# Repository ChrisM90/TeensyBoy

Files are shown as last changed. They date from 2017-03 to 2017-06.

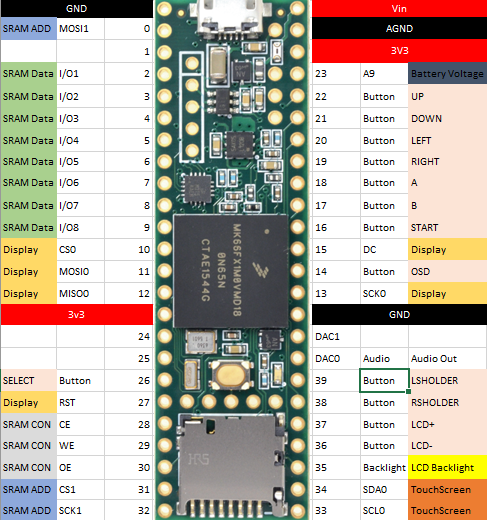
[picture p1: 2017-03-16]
Teensy Pinout.PNG

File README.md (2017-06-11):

New best FPS achieved 5.7 :-) 

First revision PCB design complete and awaiting fabrication.

Do To's:

1) Finish sound implementation.
2) Serious optimization and code cleanup.
3) Gameboy colour compatibility.
4) Cartridge connector to play real games?
5) Functionality to rip ROM's to SD card?
6) Proper hardware explanation and documentation.

If you feel inclined to donate:
Bitcoin:  1EkhsVgQydefFFrJgEuCpkJ9TY6QsAo3og

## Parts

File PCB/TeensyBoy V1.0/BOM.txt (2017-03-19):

Part     Value          Package

A        DTS-3          DTS-3
B        DTS-3          DTS-3
C1       100nf          C0603K
C2       10uf           C0603K
C3       10uf           C0603K
C4       220nf          C0603K
C5       330nf          C0603K
DOWN     DTS-3          DTS-3
JP1                     1X10
LEFT     DTS-3          DTS-3
Q1       2N2222A        TO18
R1       1K             R0603
R2       4K7            R0603
R3       10K            R0603
R4       10K            R0603
R5       10K            R0603
R6       10K            R0603
R7       10K            R0603
R8       10K            R0603
R9       10K            R0603
R10      10K            R0603
R11      100K           R0603
R13      27K            CT6
RIGHT    DTS-3          DTS-3
SELECT   DTS-3          DTS-3
SPK                     1X02
START    DTS-3          DTS-3 
U$1      AS7C34096A     AS7C34096A
U$2                     TEENSY-3.6_FULL
U1       LM4875         SO-8
UP       DTS-3          DTS-3

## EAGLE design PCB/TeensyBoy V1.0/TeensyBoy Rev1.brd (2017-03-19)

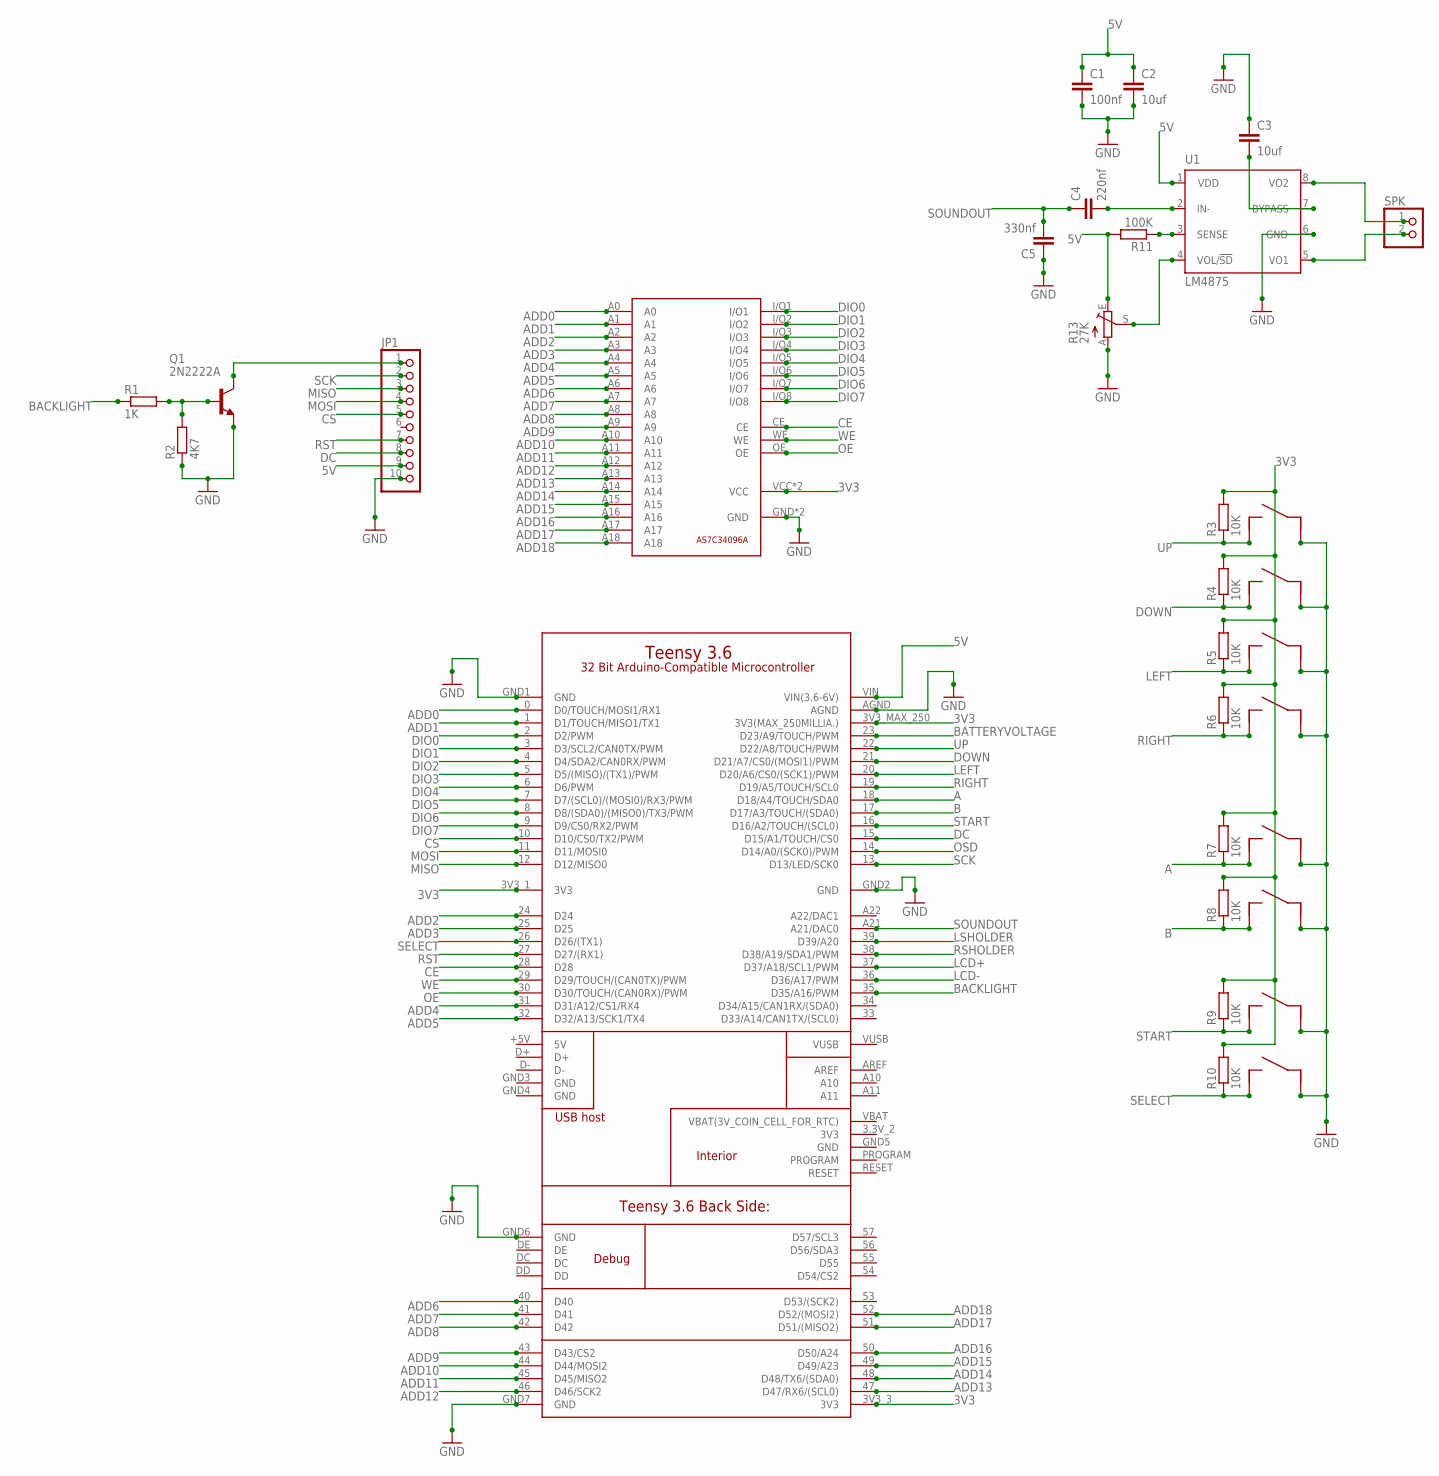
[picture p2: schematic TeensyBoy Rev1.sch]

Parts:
A: DTS-3
B: DTS-3
C1: 100nf; C0603K
C2, C3: 10uf; C0603K
C4: 220nf; C0603K
C5: 330nf; C0603K
DOWN: DTS-3
JP1: PINHD-1X10; 1X10
LEFT: DTS-3
Q1: 2N2222A; TO18
R1: 1K; R0603
R2: 4K7; R0603
R3, R4, R5, R6, R7, R8, R9, R10: 10K; R0603
R11: 100K; R0603
R13: 27K; CT6
RIGHT: DTS-3
SELECT: DTS-3
SPK: PINHD-1X2; 1X02
START: DTS-3
U1: LM4875; SO-8
U$1: AS7C34096A
U$2: TEENSY-3.6_FULL
UP: DTS-3

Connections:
3V3: R3.2, R4.2, R5.2, R6.2, R7.2, R8.2, R9.2, R10.2, U$1.VCC, U$1.VCC0 (VCC), U$2.3V3_1 (3V3), U$2.3V3_3 (3V3), U$2.3V3_MAX_250 (3V3(MAX_250MILLIA.))
5V: C1.1, C2.1, JP1.9, R11.2, R13.E, U1.1 (VDD), U$2.VIN (VIN(3.6-6V))
A: A.P$1, R7.1, U$2.18 (D18/A4/TOUCH/SDA0)
ADD0: U$1.A0, U$2.0 (D0/TOUCH/MOSI1/RX1)
ADD1: U$1.A1, U$2.1 (D1/TOUCH/MISO1/TX1)
ADD2: U$1.A2, U$2.24 (D24)
ADD3: U$1.A3, U$2.25 (D25)
ADD4: U$1.A4, U$2.31 (D31/A12/CS1/RX4)
ADD5: U$1.A5, U$2.32 (D32/A13/SCK1/TX4)
ADD6: U$1.A6, U$2.40 (D40)
ADD7: U$1.A7, U$2.41 (D41)
ADD8: U$1.A8, U$2.42 (D42)
ADD9: U$1.A9, U$2.43 (D43/CS2)
ADD10: U$1.A10, U$2.44 (D44/MOSI2)
ADD11: U$1.A11, U$2.45 (D45/MISO2)
ADD12: U$1.A12, U$2.46 (D46/SCK2)
ADD13: U$1.A13, U$2.47 (D47/RX6/(SCL0))
ADD14: U$1.A14, U$2.48 (D48/TX6/(SDA0))
ADD15: U$1.A15, U$2.49 (D49/A23)
ADD16: U$1.A16, U$2.50 (D50/A24)
ADD17: U$1.A17, U$2.51 (D51/(MISO2))
ADD18: U$1.A18, U$2.52 (D52/(MOSI2))
B: B.P$1, R8.1, U$2.17 (D17/A3/TOUCH/(SDA0))
BACKLIGHT: R1.1, U$2.35 (D35/A16/PWM)
BATTERYVOLTAGE: U$2.23 (D23/A9/TOUCH/PWM)
CE: U$1.CE, U$2.28 (D28)
CS: JP1.5, U$2.10 (D10/CS0/TX2/PWM)
DC: JP1.8, U$2.15 (D15/A1/TOUCH/CS0)
DIO0: U$1.I/O1, U$2.2 (D2/PWM)
DIO1: U$1.I/O2, U$2.3 (D3/SCL2/CAN0TX/PWM)
DIO2: U$1.I/O3, U$2.4 (D4/SDA2/CAN0RX/PWM)
DIO3: U$1.I/O4, U$2.5 (D5/(MISO)/(TX1)/PWM)
DIO4: U$1.I/O5, U$2.6 (D6/PWM)
DIO5: U$1.I/O6, U$2.7 (D7/(SCL0)/(MOSI0)/RX3/PWM)
DIO6: U$1.I/O7, U$2.8 (D8/(SDA0)/(MISO0)/TX3/PWM)
DIO7: U$1.I/O8, U$2.9 (D9/CS0/RX2/PWM)
DOWN: DOWN.P$1, R4.1, U$2.21 (D21/A7/CS0/(MOSI1)/PWM)
GND: A.P$2, B.P$2, C1.2, C2.2, C3.1, C5.1, DOWN.P$2, JP1.10, LEFT.P$2, Q1.1 (E), R2.1, R13.A, RIGHT.P$2, SELECT.P$2, START.P$2, U1.6 (GND), U$1.GND, U$1.GND0 (GND), U$2.AGND, U$2.GND1 (GND), U$2.GND2 (GND), U$2.GND6 (GND), U$2.GND7 (GND), UP.P$2
LCD+: U$2.37 (D37/A18/SCL1/PWM)
LCD-: U$2.36 (D36/A17/PWM)
LEFT: LEFT.P$1, R5.1, U$2.20 (D20/A6/CS0/(SCK1)/PWM)
LSHOLDER: U$2.39 (D39/A20)
MISO: JP1.3, U$2.12 (D12/MISO0)
MOSI: JP1.4, U$2.11 (D11/MOSI0)
unnamed: JP1.1, Q1.3 (C)
unnamed: Q1.2 (B), R1.2, R2.2
unnamed: C3.2, U1.7 (BYPASS)
unnamed: C4.2, U1.2 (IN-)
unnamed: R11.1, U1.3 (SENSE)
unnamed: SPK.1, U1.8 (VO2)
unnamed: SPK.2, U1.5 (VO1)
unnamed: R13.S, U1.4 (VOL/!SD)
OE: U$1.OE, U$2.30 (D30/TOUCH/(CAN0RX)/PWM)
OSD: U$2.14 (D14/A0/(SCK0)/PWM)
RIGHT: R6.1, RIGHT.P$1, U$2.19 (D19/A5/TOUCH/SCL0)
RSHOLDER: U$2.38 (D38/A19/SDA1/PWM)
RST: JP1.7, U$2.27 (D27/(RX1))
SCK: JP1.2, U$2.13 (D13/LED/SCK0)
SELECT: R10.1, SELECT.P$1, U$2.26 (D26/(TX1))
SOUNDOUT: C4.1, C5.2, U$2.A21 (A21/DAC0)
START: R9.1, START.P$1, U$2.16 (D16/A2/TOUCH/(SCL0))
UP: R3.1, U$2.22 (D22/A8/TOUCH/PWM), UP.P$1
WE: U$1.WE, U$2.29 (D29/TOUCH/(CAN0TX)/PWM)

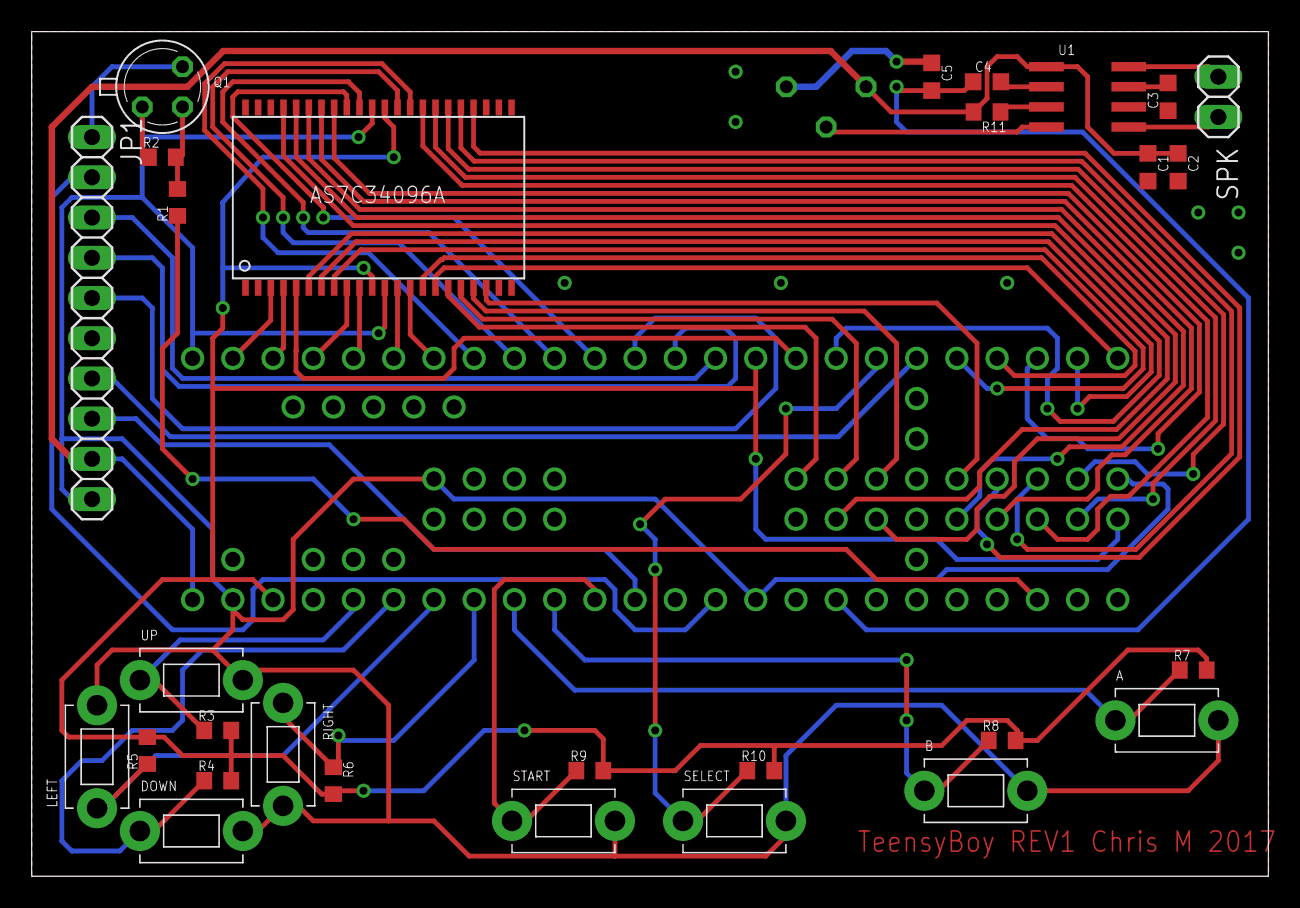
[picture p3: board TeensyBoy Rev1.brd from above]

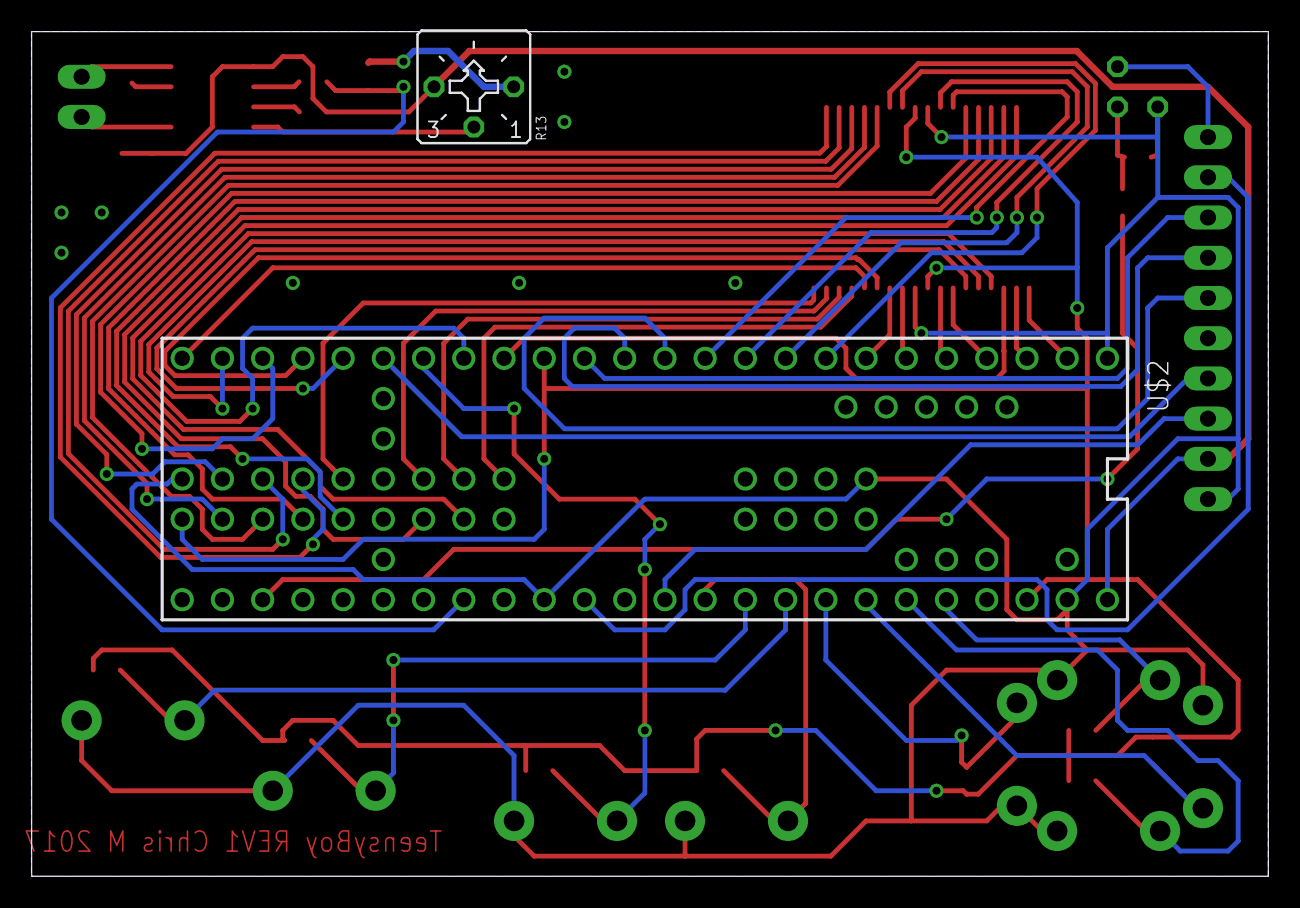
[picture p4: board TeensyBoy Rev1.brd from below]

Board: 2 copper layers, 78.1 x 53.3 mm, 31 parts (2 on the bottom side), 57 nets.

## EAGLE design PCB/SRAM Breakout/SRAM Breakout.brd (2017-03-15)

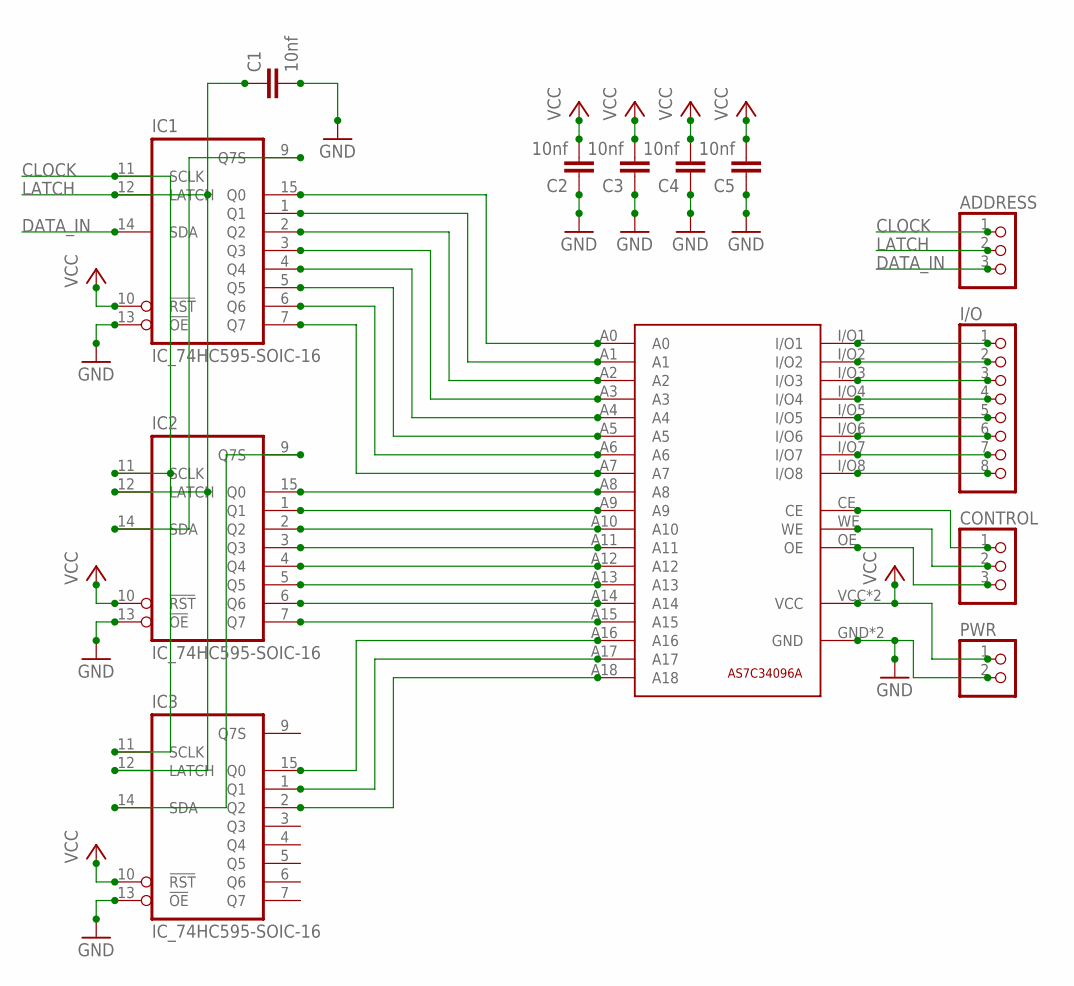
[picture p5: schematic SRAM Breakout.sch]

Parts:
ADDRESS: PINHD-1X3/90; 1X03/90
C1, C2, C3, C4, C5: 10nf; C0603
CONTROL: PINHD-1X3/90; 1X03/90
I/O: PINHD-1X8/90; 1X08/90
IC1, IC2, IC3: IC_74HC595-SOIC-16; SOIC-16
PWR: PINHD-1X2/90; 1X02/90
U$1: AS7C34096A

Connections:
CLOCK: ADDRESS.1, IC1.11 (SCLK), IC2.11 (SCLK), IC3.11 (SCLK)
DATA_IN: ADDRESS.3, IC1.14 (SDA)
GND: C1.2, C2.1, C3.1, C4.1, C5.1, IC1.13 (!OE), IC2.13 (!OE), IC3.13 (!OE), PWR.2, U$1.GND, U$1.GND0 (GND)
LATCH: ADDRESS.2, C1.1, IC1.12 (LATCH), IC2.12 (LATCH), IC3.12 (LATCH)
unnamed: IC1.9 (Q7S), IC2.14 (SDA)
unnamed: IC2.9 (Q7S), IC3.14 (SDA)
unnamed: I/O.1, U$1.I/O1
unnamed: IC1.15 (Q0), U$1.A0
unnamed: IC1.1 (Q1), U$1.A1
unnamed: IC1.2 (Q2), U$1.A2
unnamed: IC1.3 (Q3), U$1.A3
unnamed: IC1.4 (Q4), U$1.A4
unnamed: IC1.5 (Q5), U$1.A5
unnamed: IC1.6 (Q6), U$1.A6
unnamed: IC1.7 (Q7), U$1.A7
unnamed: IC2.15 (Q0), U$1.A8
unnamed: IC2.1 (Q1), U$1.A9
unnamed: IC2.2 (Q2), U$1.A10
unnamed: IC2.3 (Q3), U$1.A11
unnamed: IC2.4 (Q4), U$1.A12
unnamed: IC2.5 (Q5), U$1.A13
unnamed: IC2.6 (Q6), U$1.A14
unnamed: IC2.7 (Q7), U$1.A15
unnamed: IC3.15 (Q0), U$1.A16
unnamed: IC3.1 (Q1), U$1.A17
unnamed: IC3.2 (Q2), U$1.A18
unnamed: I/O.2, U$1.I/O2
unnamed: I/O.3, U$1.I/O3
unnamed: I/O.4, U$1.I/O4
unnamed: I/O.5, U$1.I/O5
unnamed: I/O.6, U$1.I/O6
unnamed: I/O.7, U$1.I/O7
unnamed: I/O.8, U$1.I/O8
unnamed: CONTROL.1, U$1.CE
unnamed: CONTROL.2, U$1.WE
unnamed: CONTROL.3, U$1.OE
VCC: C2.2, C3.2, C4.2, C5.2, IC1.10 (!RST), IC2.10 (!RST), IC3.10 (!RST), PWR.1, U$1.VCC, U$1.VCC0 (VCC)

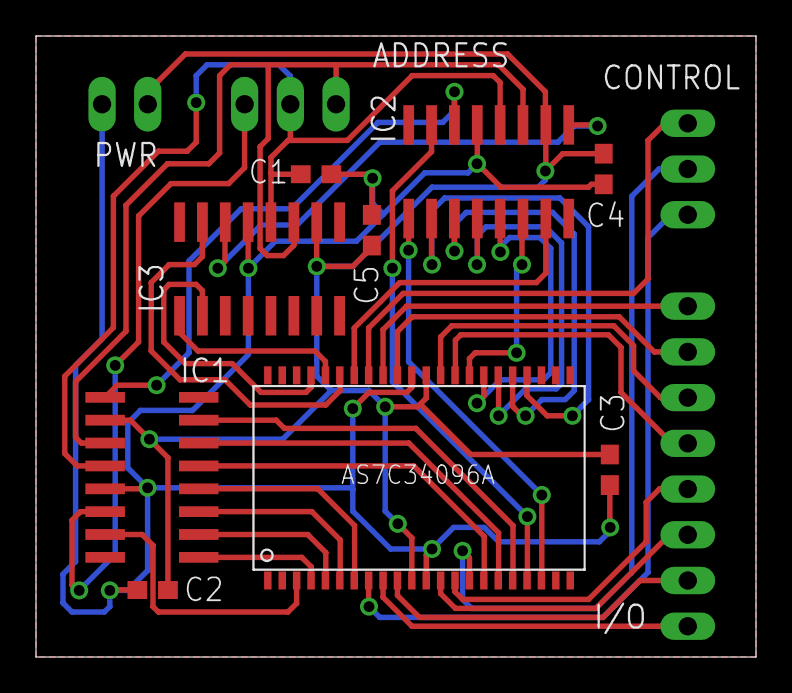
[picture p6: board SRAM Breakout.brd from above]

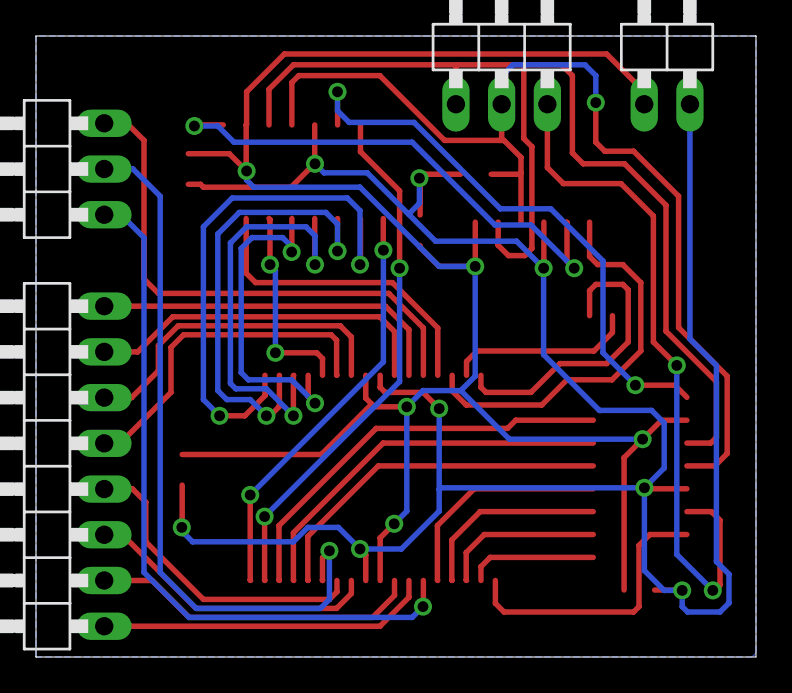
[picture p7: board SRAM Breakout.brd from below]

Board: 2 copper layers, 40.0 x 34.5 mm, 13 parts (4 on the bottom side), 37 nets.

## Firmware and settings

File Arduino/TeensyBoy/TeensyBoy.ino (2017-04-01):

/* TeenyBoy code is placed under the MIT license
   Copyright (c) 2017 Chris Mortimer

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
   THE SOFTWARE IS PROVIDED "AS IS", WITHOUT WARRANTY OF ANY KIND,
   EXPRESS OR IMPLIED, INCLUDING BUT NOT LIMITED TO THE WARRANTIES OF
   MERCHANTABILITY, FITNESS FOR A PARTICULAR PURPOSE AND
   NONINFRINGEMENT. IN NO EVENT SHALL THE AUTHORS OR COPYRIGHT HOLDERS
   BE LIABLE FOR ANY CLAIM, DAMAGES OR OTHER LIABILITY, WHETHER IN AN
   ACTION OF CONTRACT, TORT OR OTHERWISE, ARISING FROM, OUT OF OR IN
   CONNECTION WITH THE SOFTWARE OR THE USE OR OTHER DEALINGS IN THE
   SOFTWARE.
*/
#include <SD.h>
#include <SD_t3.h>
#include <SPI.h>
#include "GBA.h"
#include "GBC.h"

File FROM;
GBA GBAEmulator;

void setup()
{
  delay(2000);
  
  Serial.begin(250000);
  
  SD.begin(BUILTIN_SDCARD);
  FROM = SD.open("/MK/MK.gba", FILE_READ);

  GBAEmulator.Initilise(&FROM);

  ARM_DEMCR |= ARM_DEMCR_TRCENA;
  ARM_DWT_CTRL |= ARM_DWT_CTRL_CYCCNTENA;

  Serial.println("Checking and Resetting Memory...");
  Serial.flush();

  unsigned long WriteTime = 0.0;
  unsigned long ReadTime = 0.0;
  unsigned long WriteTimeSeq = 0.0;
  unsigned long ReadTimeSeq = 0.0;
  unsigned long AddressTime = 0.0;
  unsigned long AddressTimeSeq = 0.0;
  unsigned long Timer = 0;

  for(int i = 0; i < 30; i++)
  {
    Timer = ARM_DWT_CYCCNT;
    SPIRAMWrite((i * 10), 128);
    Timer = ARM_DWT_CYCCNT - Timer;
    WriteTime += Timer;
  
    Timer = ARM_DWT_CYCCNT;
    SPIRAMWrite((i * 10) + 1, 128);
    Timer = ARM_DWT_CYCCNT - Timer;
    WriteTimeSeq += Timer;
    
    Timer = ARM_DWT_CYCCNT;
    SPIRAMRead((i * 10));
    Timer = ARM_DWT_CYCCNT - Timer;
    ReadTime += Timer;
  
    Timer = ARM_DWT_CYCCNT;
    SPIRAMRead((i * 10) + 1);
    Timer = ARM_DWT_CYCCNT - Timer;
    ReadTimeSeq += Timer;

    Timer = ARM_DWT_CYCCNT;
    SetAddress((i * 10));
    Timer = ARM_DWT_CYCCNT - Timer;
    AddressTime += Timer;

    Timer = ARM_DWT_CYCCNT;
    SetAddress((i * 10) + 1);
    Timer = ARM_DWT_CYCCNT - Timer;
    AddressTimeSeq += Timer;

    SPIRAMRead(0);
  }

  float timemulti = 1.0f / 240; //1 us divided by 240Mhz

  Serial.println("Memory Read Time: " + String(((float)ReadTime / 30.0f) * timemulti) + "us");
  Serial.println("Memory Write Time: " + String(((float)WriteTime / 30.0f) * timemulti) + "us");
  
  Serial.println("Memory Read Time Seq: " + String(((float)ReadTimeSeq / 30.0f) * timemulti) + "us");
  Serial.println("Memory Write Time Seq: " + String(((float)WriteTimeSeq / 30.0f) * timemulti) + "us");

  Serial.println("Memory Address Time: " + String(((float)AddressTime / 30.0f) * timemulti) + "us");
  Serial.println("Memory Address Time Seq: " + String(((float)AddressTimeSeq / 30.0f) * timemulti) + "us");
  
  while(true)
  {
    uint8_t val = 0;
    bool failed = false;
    for(uint32_t i = 0; i < 0x80000; i++)
    {
      SPIRAMWrite(i, val);
      uint8_t value = SPIRAMRead(i);
  
      if(value != val)
      {
        Serial.println("Memory Check Failed at :" + String(i, DEC) + " W: " + String(val, DEC) + " R: " + String(value, DEC));
        Serial.flush();
        failed = true;
        break;
      }
      SPIRAMWrite(i, 0);
      val++;
    }
    
    if(!failed)
    {
      Serial.println("Ram Test: Passed");
      break;
    }
  
    delay(1000);
  }
  
  Serial.println("Init Complete");
  Serial.println("Emulation Starting..");
}

void loop()
{
  GBAEmulator.Update();
}

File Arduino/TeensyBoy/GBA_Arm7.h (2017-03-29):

/* TeenyBoy code is placed under the MIT license
   Copyright (c) 2017 Chris Mortimer

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
   THE SOFTWARE IS PROVIDED "AS IS", WITHOUT WARRANTY OF ANY KIND,
   EXPRESS OR IMPLIED, INCLUDING BUT NOT LIMITED TO THE WARRANTIES OF
   MERCHANTABILITY, FITNESS FOR A PARTICULAR PURPOSE AND
   NONINFRINGEMENT. IN NO EVENT SHALL THE AUTHORS OR COPYRIGHT HOLDERS
   BE LIABLE FOR ANY CLAIM, DAMAGES OR OTHER LIABILITY, WHETHER IN AN
   ACTION OF CONTRACT, TORT OR OTHERWISE, ARISING FROM, OUT OF OR IN
   CONNECTION WITH THE SOFTWARE OR THE USE OR OTHER DEALINGS IN THE
   SOFTWARE.
*/

#ifndef Arm7_h
#define Arm7_h

#include <inttypes.h>
#include <Arduino.h>

#define REG_BASE 0x4000000
#define PAL_BASE 0x5000000
#define VRAM_BASE 0x6000000
#define OAM_BASE 0x7000000

#define DISPSTAT 0x4
#define VCOUNT 0x6

#define BG0CNT 0x8
#define BG1CNT 0xA
#define BG2CNT 0xC
#define BG3CNT 0xE

#define BG0HOFS 0x10
#define BG0VOFS 0x12
#define BG1HOFS 0x14
#define BG1VOFS 0x16
#define BG2HOFS 0x18
#define BG2VOFS 0x1A
#define BG3HOFS 0x1C
#define BG3VOFS 0x1E

#define BG2PA 0x20
#define BG2PB 0x22
#define BG2PC 0x24
#define BG2PD 0x26
#define BG2X_L 0x28
#define BG2X_H 0x2A
#define BG2Y_L 0x2C
#define BG2Y_H 0x2E
#define BG3PA 0x30
#define BG3PB 0x32
#define BG3PC 0x34
#define BG3PD 0x36
#define BG3X_L 0x38
#define BG3X_H 0x3A
#define BG3Y_L 0x3C
#define BG3Y_H 0x3E

#define BLDCNT 0x50
#define BLDALPHA 0x52
#define BLDY 0x54

#define SOUNDCNT_L 0x80
#define SOUNDCNT_H 0x82
#define SOUNDCNT_X 0x84

#define FIFO_A_L 0xA0
#define FIFO_A_H 0xA2
#define FIFO_B_L 0xA4
#define FIFO_B_H 0xA6

#define DMA0SAD 0xB0
#define DMA0DAD 0xB4
#define DMA0CNT_L 0xB8
#define DMA0CNT_H 0xBA
#define DMA1SAD 0xBC
#define DMA1DAD 0xC0
#define DMA1CNT_L 0xC4
#define DMA1CNT_H 0xC6
#define DMA2SAD 0xC8
#define DMA2DAD 0xCC
#define DMA2CNT_L 0xD0
#define DMA2CNT_H 0xD2
#define DMA3SAD 0xD4
#define DMA3DAD 0xD8
#define DMA3CNT_L 0xDC
#define DMA3CNT_H 0xDE

#define TM0D 0x100
#define TM0CNT 0x102
#define TM1D 0x104
#define TM1CNT 0x106
#define TM2D 0x108
#define TM2CNT 0x10A
#define TM3D 0x10C
#define TM3CNT 0x10E

#define KEYINPUT 0x130
#define KEYCNT 0x132
#define IE0 0x200
#define IF 0x202
#define IME 0x208

#define HALTCNT 0x300

#define biosRamMask 0x3FFF //BIOS ROM 16KB
#define ewRamMask 0x3FFFF  //External Work Ram 256KB
#define iwRamMask 0x7FFF   //Internal MCU Memory 32KB
#define ioRegMask 0x4FF    //IO RAM 1KB 
#define vRamMask 0x1FFFF   //Video RAM 96KB
#define palRamMask 0x3FF   //Palettes RAM 1KB
#define oamRamMask 0x3FF   //Object Attribute RAM 1KB
#define sRamMask 0xFFFF    //Cartridge RAM 64KB
#define eeMask 0xFFFF

#define ewRamStart  0x00000000 //0x00000 - 0x3FFFF = 0x3FFFF
#define iwRamStart  0x00040000 //0x40000 - 0x47FFF = 0x7FFF
#define ioRegStart  0x00048000 //0x48000 - 0x484FF = 0x4FF
#define vRamStart   0x00048500 //0x48500 - 0x684FF = 0x1FFFF
#define palRamStart 0x00068500 //0x68500 - 0x688FF = 0x3FF
#define oamRamStart 0x00068900 //0x68900 - 0x68CFF = 0x3FF
#define sRamStart   0x00068D00 //0x68D00 - 0x78CFF = 0xFFFF
#define eeStart     0x00078D00 //0x78D00 - 0x88CFF = 0xFFFF

class Processor
{
  public:
    //Variables
    //CPSR Bit Definitions
    uint32_t N_BIT = 31;
    uint32_t Z_BIT = 30;
    uint32_t C_BIT = 29;
    uint32_t V_BIT = 28;
    uint32_t I_BIT = 7;
    uint32_t F_BIT = 6;
    uint32_t T_BIT = 5;
    
    uint32_t N_MASK = (1 << N_BIT);
    uint32_t Z_MASK = (1 << Z_BIT);
    uint32_t C_MASK = (1 << C_BIT);
    uint32_t V_MASK = (1 << V_BIT);
    uint32_t I_MASK = (1 << I_BIT);
    uint32_t F_MASK = (1 << F_BIT);
    uint32_t T_MASK = (1 << T_BIT);

    int32_t Cycles = 0;
    int32_t timerCycles = 0;
    int32_t soundCycles = 0;
    uint32_t registers[16];
    uint32_t cpsr = 0;
    uint32_t waitCycles = 0;
    int32_t bgx[2];
    int32_t bgy[2];
    bool cpuHalted = false;
    uint8_t OAMRAM[0x3FF];
    uint8_t IOREG[0x4FF];
    uint16_t keyState = 0x3FF;

    //Methods
    Processor();
    void Print(const char* value, uint32_t v);
    void CreateCores(class Processor *par, class File *rom, bool SkipBios);
    bool ArmState();
    bool SPSRExists();
    uint32_t GetWaitCycles();
    uint32_t GetSPSR();
    void SetSPSR(uint32_t value);
    void SwapRegsHelper(uint32_t swapRegs[]);
    void SwapRegisters(uint32_t bank);
    void WriteCpsr(uint32_t newCpsr);
    void EnterException(uint32_t mode, uint32_t vector, bool interruptDisabled, bool fiqDisabled);
    void RequestIrq(uint16_t irq);
    void FireIrq();
    void Reset(bool skipBios);
    void Halt();
    void ReloadQueue();
    void UpdateTimer(uint16_t timer, uint32_t cycles, bool countUp);
    void UpdateTimers();
    void UpdateKeyState();
    void UpdateSound();
    void Execute(int cycles);

    void Reset();
    
    void HBlankDma();
    void VBlankDma();
    void FifoDma(uint8_t channel);
    void DmaTransfer(uint8_t channel);
    void WriteDmaControl(uint8_t channel);
    void WriteTimerControl(uint32_t timer, uint32_t newCnt);
    
    uint8_t ReadU8(uint32_t address, uint32_t RAMRange);
    uint16_t ReadU16(uint32_t address, uint32_t RAMRange);
    uint32_t ReadU32(uint32_t address, uint32_t RAMRange);
    
    void WriteU8(uint32_t address, uint32_t RAMRange, uint8_t value);
    void WriteU16(uint32_t address, uint32_t RAMRange, uint16_t value);
    void WriteU32(uint32_t address, uint32_t RAMRange, uint32_t value);
    
    uint32_t ReadUnreadable();
    uint8_t ReadNop8(uint32_t address);
    uint16_t ReadNop16(uint32_t address);
    uint32_t ReadNop32(uint32_t address);
    uint8_t  ReadBIOS8(uint32_t address);
    uint16_t ReadBIOS16(uint32_t address);
    uint32_t ReadBIOS32(uint32_t address);
    uint8_t ReadEwRam8(uint32_t address);
    uint16_t ReadEwRam16(uint32_t address);
    uint32_t ReadEwRam32(uint32_t address);
    uint8_t ReadIwRam8(uint32_t address);
    uint16_t ReadIwRam16(uint32_t address);
    uint32_t ReadIwRam32(uint32_t address);
    uint8_t ReadIO8(uint32_t address);
    uint16_t ReadIO16(uint32_t address);
    uint32_t ReadIO32(uint32_t address);
    uint8_t ReadPalRam8(uint32_t address);
    uint16_t ReadPalRam16(uint32_t address);
    uint32_t ReadPalRam32(uint32_t address);
    uint8_t ReadVRam8(uint32_t address);
    uint16_t ReadVRam16(uint32_t address);
    uint32_t ReadVRam32(uint32_t address);
    uint8_t ReadOamRam8(uint32_t address);
    uint16_t ReadOamRam16(uint32_t address);
    uint32_t ReadOamRam32(uint32_t address);
    uint8_t  ReadROM8(uint32_t address, uint8_t bank);
    uint16_t ReadROM16(uint32_t address, uint8_t bank);
    uint32_t ReadROM32(uint32_t address, uint8_t bank);
    uint8_t ReadSRam8(uint32_t address);
    uint16_t ReadSRam16(uint32_t address);
    uint32_t ReadSRam32(uint32_t address);
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

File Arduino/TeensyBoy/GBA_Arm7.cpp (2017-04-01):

/* TeenyBoy code is placed under the MIT license
   Copyright (c) 2017 Chris Mortimer

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
   THE SOFTWARE IS PROVIDED "AS IS", WITHOUT WARRANTY OF ANY KIND,
   EXPRESS OR IMPLIED, INCLUDING BUT NOT LIMITED TO THE WARRANTIES OF
   MERCHANTABILITY, FITNESS FOR A PARTICULAR PURPOSE AND
   NONINFRINGEMENT. IN NO EVENT SHALL THE AUTHORS OR COPYRIGHT HOLDERS
   BE LIABLE FOR ANY CLAIM, DAMAGES OR OTHER LIABILITY, WHETHER IN AN
   ACTION OF CONTRACT, TORT OR OTHERWISE, ARISING FROM, OUT OF OR IN
   CONNECTION WITH THE SOFTWARE OR THE USE OR OTHER DEALINGS IN THE
   SOFTWARE.
*/

#include "GBA_Arm7.h"
#include "GBA_ArmCore.h"
#include "GBA_ThumbCore.h"
#include "Bios.h"
#include "GBA_SoundManager.h"
#include <SD.h>
#include <SD_t3.h>

//---------------------Memory----------------------------//
bool inUnreadable = false;
uint32_t dmaRegs[4][4];
uint32_t timerCnt[4];

uint32_t romBank1Mask = 0;
uint32_t romBank2Mask = 0;
uint32_t bankSTimes[0x10];
uint32_t bankNTimes[0x10];
uint8_t RomBankCount = 0;

//-------------------------VGA--------------------------//

const uint8_t VramBlockSize = 64;
const uint8_t PalBlockSize = 32;
bool EnableVRUpdating = true;

//----------------------------CPU-----------------------//
//CPU Mode Definitions
const uint32_t USR = 0x10;
const uint32_t FIQ = 0x11;
const uint32_t IRQ = 0x12;
const uint32_t SVC = 0x13;
const uint32_t ABT = 0x17;
const uint32_t UND = 0x1B;
const uint32_t SYS = 0x1F;
    
//Bank Registers
uint32_t bankedFIQ[7];
uint32_t bankedIRQ[2];
uint32_t bankedSVC[2];
uint32_t bankedABT[2];
uint32_t bankedUND[2];

//Saved CPSR's
uint32_t spsrFIQ = 0;
uint32_t spsrIRQ = 0;
uint32_t spsrSVC = 0;
uint32_t spsrABT = 0;
uint32_t spsrUND = 0;

#define CE 28
#define WE 29
#define OE 30

#define DIO0 2 //D0
#define DIO1 3 //A12
#define DIO2 4 //A13
#define DIO3 5 //D7
#define DIO4 6 //D4
#define DIO5 7 //D2
#define DIO6 8 //D3
#define DIO7 9 //C3

#define ADD0 0   //B16
#define ADD1 1   //B17
#define ADD2 24  //E26
#define ADD3 25  //A5 
#define ADD4 31  //B10
#define ADD5 32  //B11
#define ADD6 40  //A28 
#define ADD7 41  //A29 
#define ADD8 42  //A26 
#define ADD9 43  //B20
#define ADD10 44 //B22
#define ADD11 45 //B23 
#define ADD12 46 //B21 
#define ADD13 47 //D8 
#define ADD14 48 //D9 
#define ADD15 49 //B4 
#define ADD16 50 //B5 
#define ADD17 51 //D14
#define ADD18 52 //D13

ArmCore armCore;
ThumbCore thumbCore;
SoundManager sound;
Processor *SelfReference;
File *ROM;

Processor::Processor()
{
  //Memory Data IO
  pinMode(DIO0, INPUT); //IO 0
  pinMode(DIO1, INPUT); //IO 1
  pinMode(DIO2, INPUT); //IO 2
  pinMode(DIO3, INPUT); //IO 3
  pinMode(DIO4, INPUT); //IO 4
  pinMode(DIO5, INPUT); //IO 5
  pinMode(DIO6, INPUT); //IO 6
  pinMode(DIO7, INPUT); //IO 7

  //Memory Control Default Read
  pinMode(CE, OUTPUT); //CE
  digitalWrite(CE, HIGH);
  pinMode(WE, OUTPUT); //WE
  digitalWrite(WE, HIGH);
  pinMode(OE, OUTPUT); //OE
  digitalWrite(OE, LOW);

  //Memory Address
  pinMode(ADD0, OUTPUT); //ADD 0
  pinMode(ADD1, OUTPUT); //ADD 1
  pinMode(ADD2, OUTPUT); //ADD 2
  pinMode(ADD3, OUTPUT); //ADD 3
  pinMode(ADD4, OUTPUT); //ADD 4
  pinMode(ADD5, OUTPUT); //ADD 5
  pinMode(ADD6, OUTPUT); //ADD 6
  pinMode(ADD7, OUTPUT); //ADD 7
  pinMode(ADD8, OUTPUT); //ADD 8
  pinMode(ADD9, OUTPUT); //ADD 9
  pinMode(ADD10, OUTPUT); //ADD 10
  pinMode(ADD11, OUTPUT); //ADD 11
  pinMode(ADD12, OUTPUT); //ADD 12
  pinMode(ADD13, OUTPUT); //ADD 13
  pinMode(ADD14, OUTPUT); //ADD 14
  pinMode(ADD15, OUTPUT); //ADD 15
  pinMode(ADD16, OUTPUT); //ADD 16
  pinMode(ADD17, OUTPUT); //ADD 17
  pinMode(ADD18, OUTPUT); //ADD 18

  digitalWrite(ADD0, LOW);
  digitalWrite(ADD1, LOW);
  digitalWrite(ADD2, LOW);
  digitalWrite(ADD3, LOW);
  digitalWrite(ADD4, LOW);
  digitalWrite(ADD5, LOW);
  digitalWrite(ADD6, LOW);
  digitalWrite(ADD7, LOW);
  digitalWrite(ADD8, LOW);
  digitalWrite(ADD9, LOW);
  digitalWrite(ADD10, LOW);
  digitalWrite(ADD11, LOW);
  digitalWrite(ADD12, LOW);
  digitalWrite(ADD13, LOW);
  digitalWrite(ADD14, LOW);
  digitalWrite(ADD15, LOW);
  digitalWrite(ADD16, LOW);
  digitalWrite(ADD17, LOW);
  digitalWrite(ADD18, LOW);
}

void Processor::CreateCores(class Processor *par, class File *rom, bool SkipBios)
{
  digitalWrite(CE, LOW);
  ROM = rom;
  SelfReference = par;
  armCore = ArmCore(SelfReference);
  thumbCore = ThumbCore(SelfReference);
  sound.StartSM(44100, SelfReference);
  LoadCartridge();
  Reset(SkipBios);
}

void Processor::Print(const char* value, uint32_t v)
{
  Serial.println(String(value) + " " + String(v, DEC));
}

bool Processor::ArmState()
{
  return (cpsr & T_MASK) != T_MASK;
}

bool Processor::SPSRExists()
{
  switch (cpsr & 0x1F)
  {
    case USR:
    case SYS:
      return false;
    case FIQ:
    case SVC:
    case ABT:
    case IRQ:
    case UND:
      return true;
    default:
      return false;
  }
}

uint32_t Processor::GetWaitCycles()
{
  uint32_t tmp = waitCycles;
  waitCycles = 0;
  return tmp;
}

uint32_t Processor::GetSPSR()
{
  switch (cpsr & 0x1f)
  {
    case USR:
    case SYS:
      return 0xFFFFFFFF;
    case FIQ:
      return spsrFIQ;
    case SVC:
      return spsrSVC;
    case ABT:
      return spsrABT;
    case IRQ:
      return spsrIRQ;
    case UND:
      return spsrUND;
    default:
      return 0; //Explode
  }
}

void Processor::SetSPSR(uint32_t value)
{
  switch (cpsr & 0x1f)
  {
    case USR:
    case SYS:
      break;
    case FIQ:
      spsrFIQ = value;
      break;
    case SVC:
      spsrSVC = value;
      break;
    case ABT:
      spsrABT = value;
      break;
    case IRQ:
      spsrIRQ = value;
      break;
    case UND:
      spsrUND = value;
      break;
  }
}

void Processor::SwapRegsHelper(uint32_t swapRegs[])
{
  uint8_t swapRegsLength = (sizeof(swapRegs)/sizeof(uint32_t));
  
  for(int32_t i = 14; i > (14 - swapRegsLength); i--)
  {
    uint32_t temp = registers[i];
    registers[i] = swapRegs[swapRegsLength - (14 -i) - 1];
    swapRegs[swapRegsLength - (14 - i) - 1] = temp;
  }
}

void Processor::SwapRegisters(uint32_t bank)
{
  switch (bank & 0x1F)
  {
    case FIQ:
      SwapRegsHelper(bankedFIQ);
      break;
    case SVC:
      SwapRegsHelper(bankedSVC);
      break;
    case ABT:
      SwapRegsHelper(bankedABT);
      break;
    case IRQ:
      SwapRegsHelper(bankedIRQ);
      break;
    case UND:
      SwapRegsHelper(bankedUND);
      break;
  }
}

void Processor::WriteCpsr(uint32_t newCpsr)
{
  if((newCpsr & 0x1F) != (cpsr & 0x1F))
  {
    //Swap out the old registers
    SwapRegisters(cpsr);
    //Swap in the new registers
    SwapRegisters(newCpsr);
  }

  cpsr = newCpsr;
}
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

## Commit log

2017-03-15 SRAM Breakout Eagle Files Added
    [SRAM Breakout.brd, SRAM Breakout.sch]
2017-03-16 IO Reg Moved to Teensy RAM Shiftout replaced
    [Arm7.cpp, TeensyBoy.ino]
2017-03-17 Colour Blend Issues Fixed
    [Arm7.cpp, ILI9341_t3DMA.cpp, TeensyBoy.ino]
2017-03-17 Skip Shift Registers Quick & Dirty
    [Arm7.cpp, ILI9341_t3DMA.cpp, TeensyBoy.ino]
2017-03-17 Ports & Pin Numbers Identified, FPS Counter
2017-03-19 First Proper Dev Board Revision
    [TeensyBoy Rev1.brd, TeensyBoy Rev1.sch]
2017-03-21 Some Fixes & Minor Cleanup
    [Arm7.cpp]
2017-03-22 Skip Bios Option Added
    [Arm7.cpp, TeensyBoy.ino]
2017-03-24 GFX Type Corrections and Buttons Added
    [Arm7.cpp, TeensyBoy.ino]
2017-03-28 GFX Bug Squashed, ROM Now Plays Correctly :-)
    [TeensyBoy.ino]
